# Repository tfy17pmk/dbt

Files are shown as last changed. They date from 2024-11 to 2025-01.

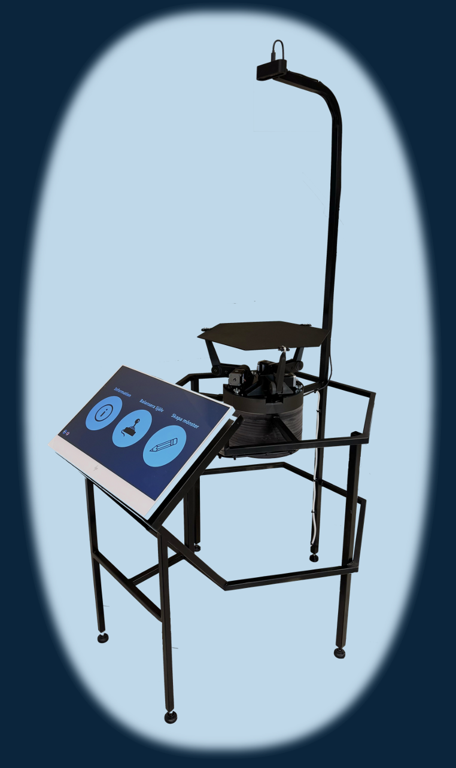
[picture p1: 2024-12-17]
GUI/assets/InfoPageOne.png

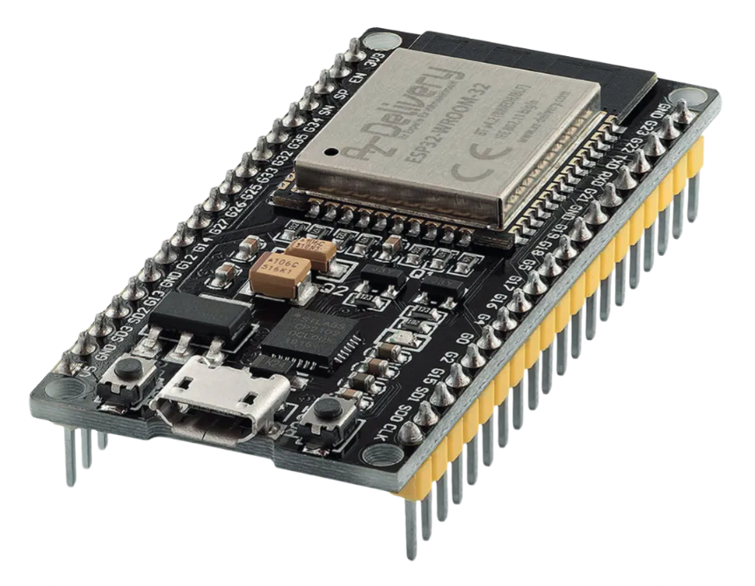
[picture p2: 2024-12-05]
GUI/assets/brain.png

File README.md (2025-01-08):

# DBT project, Ball Balancing Robot (Curiosum)

We are using Python virtual environment for development throughout the project. All the dependencies are defined in requirements.txt file, which ensures that everybody works with the same versions of dependencies. 

As for now, we have a single global virtual environment for the entire repo.

## Prerequisites

### Python version
Ensure that you use python3. Preferable version Python 3.11.2, but later versions should also be okay.

### Pip
Pip3 should be installed, if not, install with:
```
sudo apt update
sudo apt install python3-pip
pip3 --version (verify version)
```

## First setup:

### Creating environment
```
python3 -m venv dbt-venv (Linux)
python -m venv dbt-venv (Windows)
```

### Activating environment
```
source dbt-venv/bin/activate (Linux)
.\venv\Scripts\activate (Windows)
```

### Installing dependencies
```
pip install -r requirements.txt
```

## Everyday usage
Once virtual environment is created and dependencies are installed, you can follow the steps:

### Activate environment
```
source dbt-venv/bin/activate (Linux)
.\dbt-venv\Scripts\activate (Windows)
```

If you are using Windows, and get a problem with permission to run the Virtual Environment, use command:
```
Set-ExecutionPolicy Unrestricted -Scope Process
```
It can happen that you need to use it every time you open/reopen a new terminal session.

### Run applications within the environmet
```
python3 my_app.py (Linux)
python my_app.py (Windows)
```

### Deactivate environment
```
deactivate
```

## Updating dependencies
If there is a need to update the dependencies, add the new dependency to requirement.txt file.

### Update dependencies manually (Preferrable)
Add dependency on the new line in requirements.txt

### Update dependencies automatically
Otherwise, if you install the new dependency with
```
pip install new-dependency
```
add the new dependency to requirements.txt with
```
pip freeze > requirements.txt
```

OBS! Make sure to not add the dependencies that are not used/needed, if you intalled some now unused dependency before!

Don't forget to commit and push in the end of the day.

## Start program from new terminal
To start the program from a new terminal run the command:
```/home/curiadm/start_gui.sh```
It will start the program with the correct environment. 

## Maintenance of program
Password is the standard password. 
### Change text
To change the text of the pages go to ```GUI/constants.py``` here all text of the program is defined. If the text is changed be careful to check that the layout of the pages are still correct, or if the text has been changed to something that do not fit in the current canvas size. 

### Tune PID controller
Tips:

* Use a response curve to watch how the respons of the normalvector behaves. Needs good understanding of the code. 
* Write a standalone script based on the PID-process and communication while tuning. 
* Find a new plate that is truly flat that weights maximum 200g more than the current. 

## Program structure
The program uses two seperate processing devices and two different programming languages python and C++

* One Standard computer (python)
* One ESP 32 feather (C++)

The two processing devices communicate between each other using serial communication. The standard computer is responsible for running the GUI, performing image processing and performing most of the computations. The script is based around three processes and queues for robust communication between the processes. 

1. One process for navigation between the different pages in the GUI and performing the different functions in the backend of the buttons. For the backend functions in the GUI threads are also used in order to not block other functions like navigation to other pages while the ball is for instance performing a pattern. 

2. One process for performing the image analysis. The camera is started and in each frame the ball is found if there is a ball to be found. The coordnates of the ball is then put in a queue for easy access from other processes. 

3. One process for using the a PID controller to find the a new wanted normalvector of the plate. The PID controller accesses the ball coordinates in the queue and performs calculations using previous known position and current position. From this process a packet och data containing x- and y-component of the normalvector, the height of the plateand four uint_8 for controlling leds and if a homingroutine is to be run. The leds are however not implemented and used, just prepared the packet. 

The script in the ESP32 is more simple and straight forward. It is implemented using two classes and a main script. One class contains the inverse kinematics of the table, which allows easy and fast conversion between the normal vector of the plate to three motor angles. The second class governs the control of the motors. Acceleration of motors and calculates the maximum speed of each motor. The motors are then moved to the positions found by inverse kinematics. This is the performed continuos in the main script and when a new packet is received the calculationn is performed again. 

## Common errors
When the robot is plugged in a terminal window is automatically opened to allow printing of error messages

#### Camera not found
1. Check if the camera is plugged in (USB behind the screen) and on top of camera arm. 
2. Try restarting the robot (plug it out and in)
3. Change camera index, line 11 in ```webcamera.py```

#### ESP not found
Use the command ```ls /dev/tty*``` to find the port, should be named ```/dev/ttyUSB#```
1. Check if the ESP is plugged in (USB behind the screen) and micro USB underneath the robot connected to the ESP. 
2. Change the range of USB ports, line 10 in ```communication.py```

#### Lost count of steps
This error is not printed in the terminal but can be seen. The error is can be visualized if no ball is on the robot but the plate is not horizontal. 

1. Press one of the three micro switches located under the arms. This will perform the homing routine and the robot will find its steps again. 
2. Restart the robot will have the same effect. 

#### Weird starting up procedure
Sometimes  when the robots is plugged in it do not start normally. It allows the user to choose operating system. If this is the case. 

1. Wait for the timer to run out. 
2. If 1. did not work. pluggit out and in and choose the Ubuntu operating system the next time. 

#### Computer want to update
If the computer sends a message that it wants to update, just press close or remind me later.

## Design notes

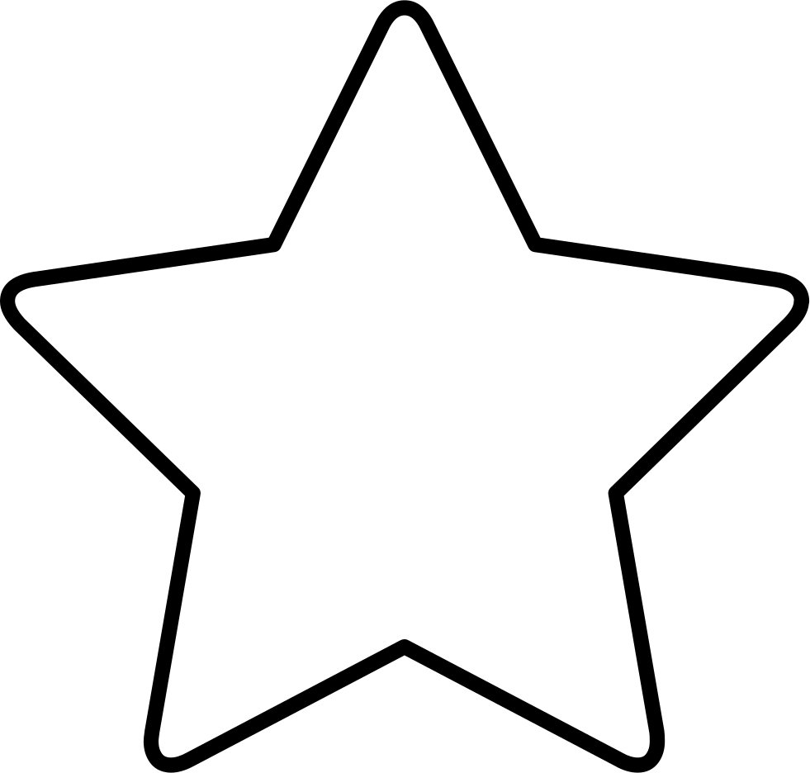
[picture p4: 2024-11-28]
GUI/assets/star.png

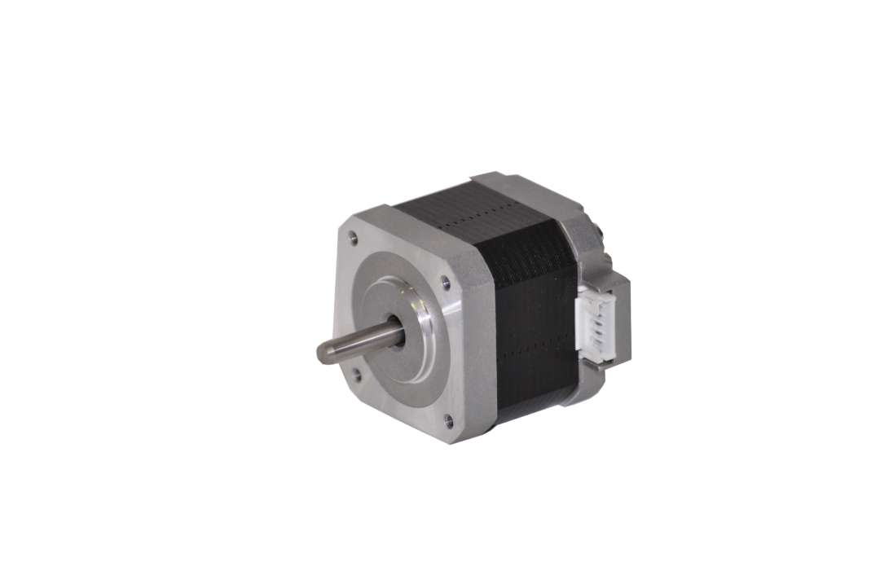
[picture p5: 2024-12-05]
GUI/assets/arm.png

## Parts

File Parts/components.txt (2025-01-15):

Camera:
    Logitech BRIO ultra HD pro
    https://www.logitech.com/sv-se/products/webcams/brio-4k-hdr-webcam.960-001106.html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

Computer:
    HP EliteOne

3st Stepper Motor:
    NEMA 17 SF2424-10B11
    https://www.elfa.se/sv/stegmotor-800nmm-2300min-sup-sup-nema-17-sanyo-denki-sf2424-10b11/p/30223848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
    
    Cable to motor:
        https://www.elfa.se/sv/bipolaer-motorkabel-med-tradar-500-mm-sanyo-denki-4835775/p/30159036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

3st Motor Driver:
    DRV8825
    https://www.electrokit.com/stegmotordrivare-drv8825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

    Capacitor: 100μF
    IMPORTANT: Dont forget to set the Vref on the driver, read the driver and motor documentation.

1st ESP32:
    HUZZAH32 ESP32 Feather
    https://www.elfa.se/sv/huzzah32-esp32-feather-kort-adafruit-3405/p/30139153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

1st PSU
    LRS-150F-36 154.8W 36V 4.3A
    https://www.elfa.se/en/embedded-switch-mode-power-supply-smps-154-8w-36v-3a-mean-well-lrs-150f-36/p/30044129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

6st BallBearing:
    Biltema 12x28x8mm
    https://www.biltema.se/bil---mc/bilreservdelar/kullager/kullager-6001-2rs-12x28x8-mm-2000050563

3st Rod End:
    Rod End 5mm Bore, 41mm Long Male Connection Gender
    https://se.rs-online.com/web/p/rod-ends/1852446

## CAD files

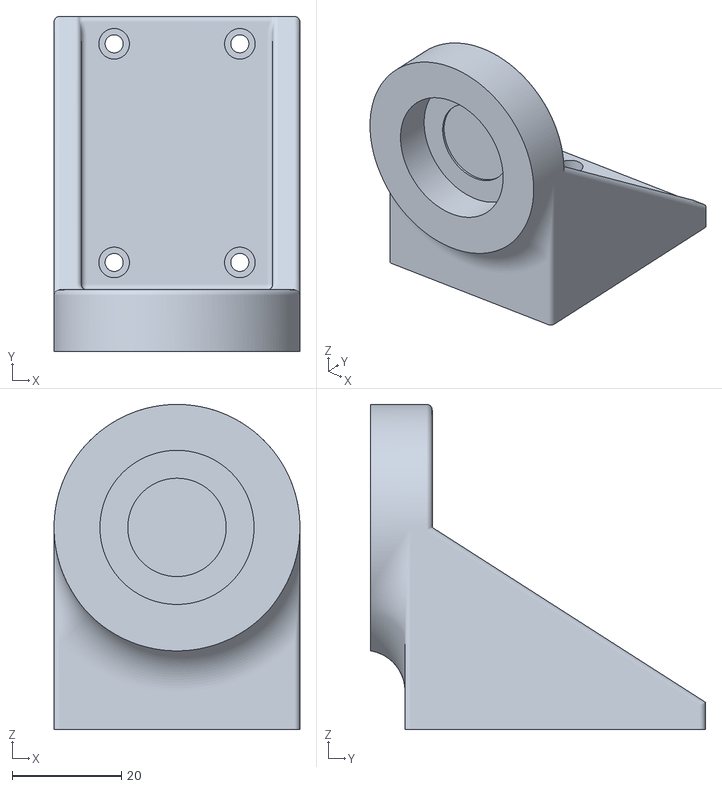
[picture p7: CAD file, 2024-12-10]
Parts/stl Files/Arm mounting/ArmMount.stl
45.0 x 61.3 x 59.5

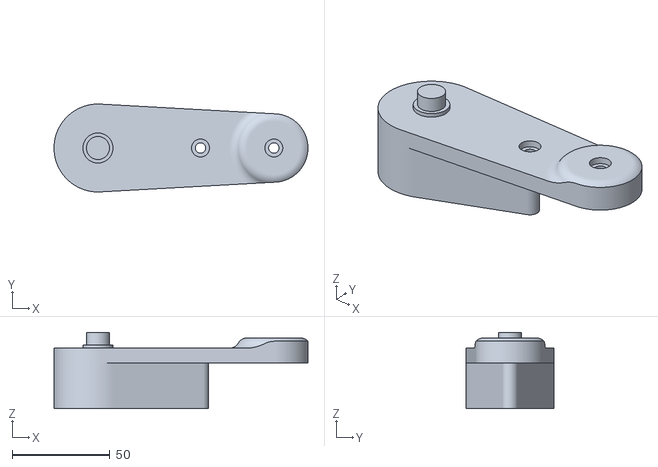
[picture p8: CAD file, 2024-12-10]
Parts/stl Files/Arm/LowerArmpartA.stl
130.0 x 45.0 x 38.9

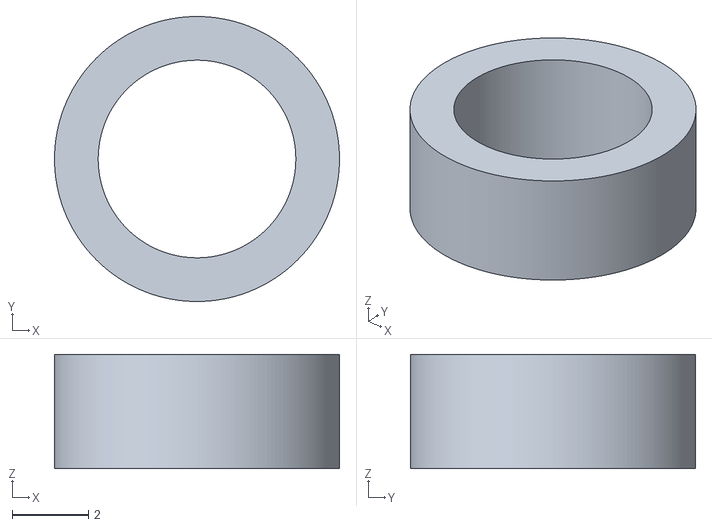
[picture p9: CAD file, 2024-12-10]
Parts/stl Files/Balance Plate Mounting Bracket/PlateBracketSpacer.stl
7.50 x 7.50 x 3.00

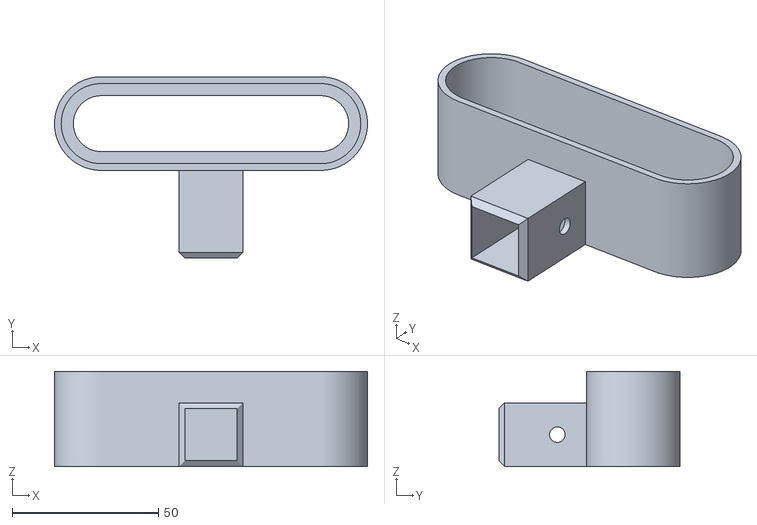
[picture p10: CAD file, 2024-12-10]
Parts/stl Files/CameraMount.stl
107.0 x 62.0 x 32.5

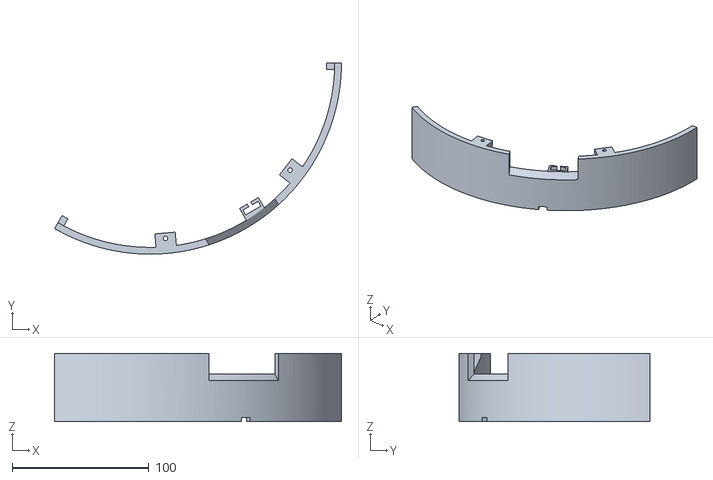
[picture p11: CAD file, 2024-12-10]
Parts/stl Files/Stand/StandPart2.stl
210.0 x 139.9 x 50.0

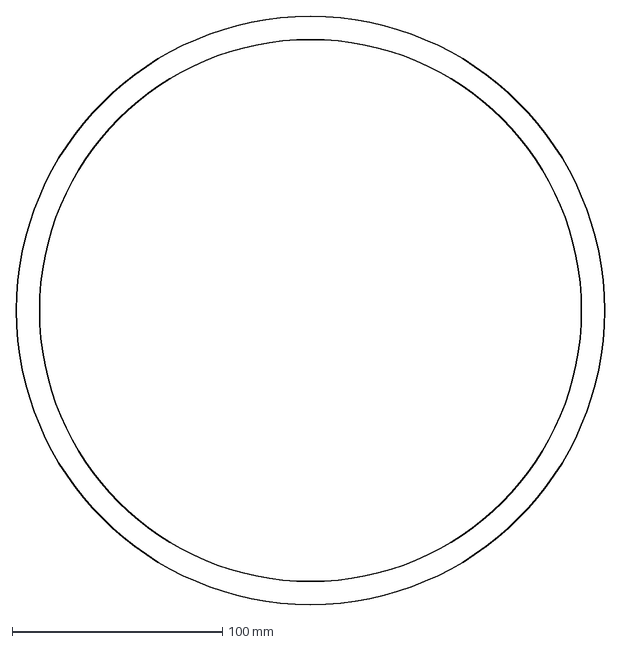
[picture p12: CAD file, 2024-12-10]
Parts/waterLaserCutting/12mmMDF/CircleBoxWall.dxf
280.0 x 280.0 mm

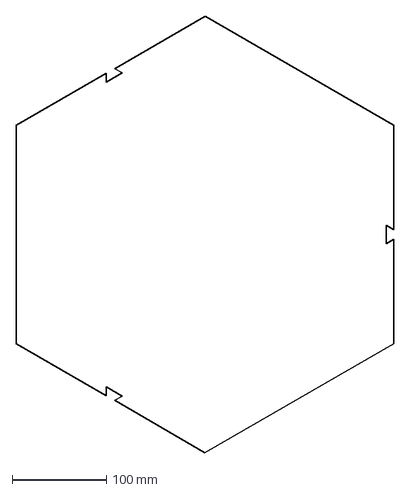
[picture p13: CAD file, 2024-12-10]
Parts/waterLaserCutting/3mmMDF/BalancePlate.dxf
400.0 x 461.9 mm

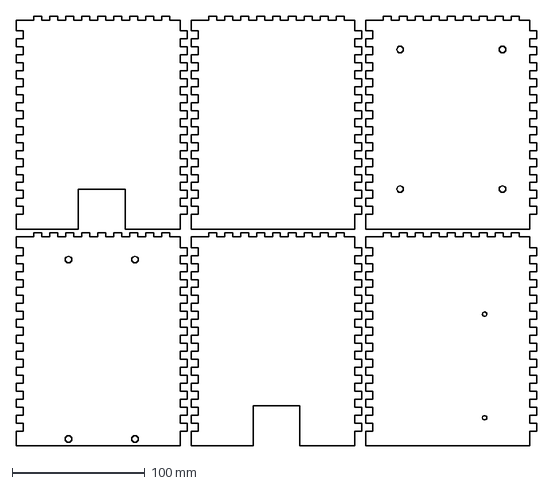
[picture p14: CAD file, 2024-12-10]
Parts/waterLaserCutting/3mmMDF/CirkularBoxInsert/SidePlates.dxf
391.4 x 323.0 mm

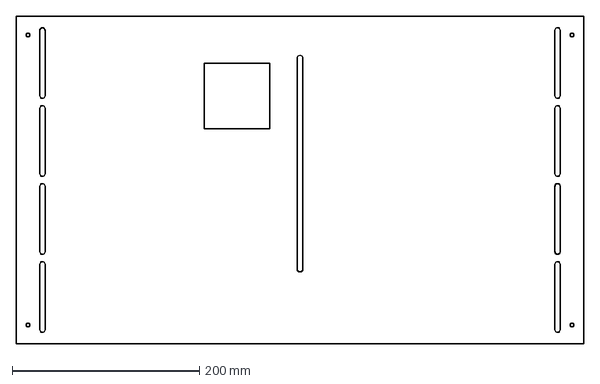
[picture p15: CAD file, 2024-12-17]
Parts/waterLaserCutting/metal/MonitorMountingPlate3mm.dxf
606.3 x 350.0 mm

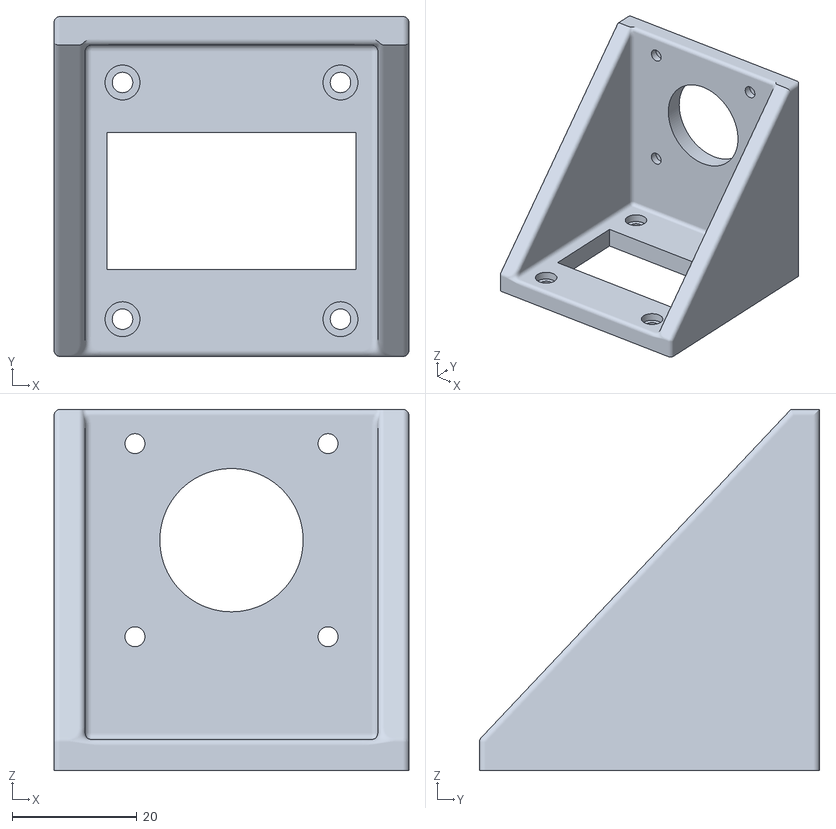
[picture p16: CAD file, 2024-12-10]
Parts/stl Files/Arm mounting/MotorBracket.stl
57.0 x 54.6 x 58.0

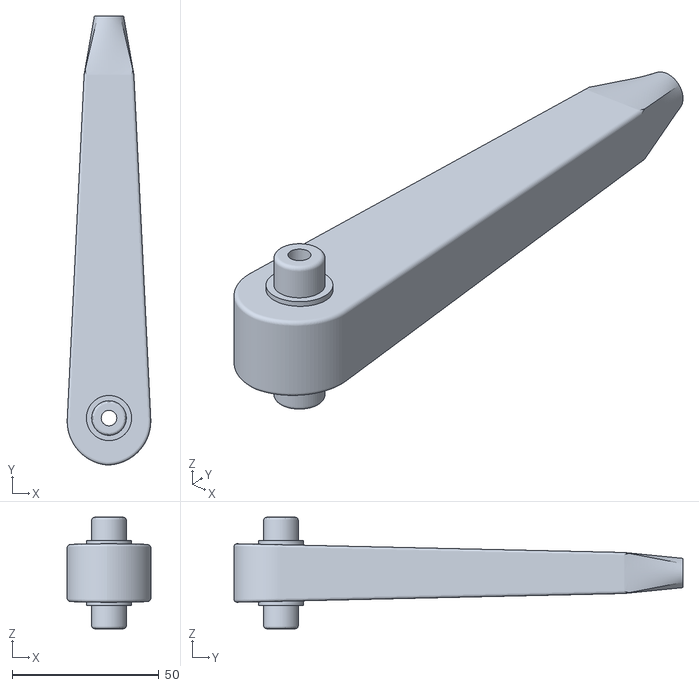
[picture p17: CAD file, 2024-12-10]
Parts/stl Files/Arm/UpperArm.stl
28.5 x 153.0 x 38.0

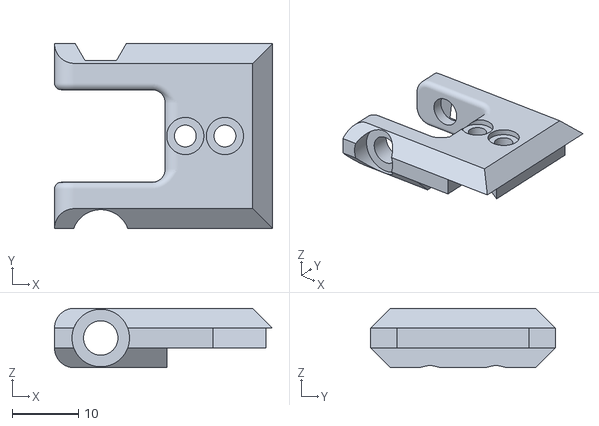
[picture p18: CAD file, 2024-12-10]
Parts/stl Files/Balance Plate Mounting Bracket/TopBracket.stl
33.0 x 28.0 x 9.00

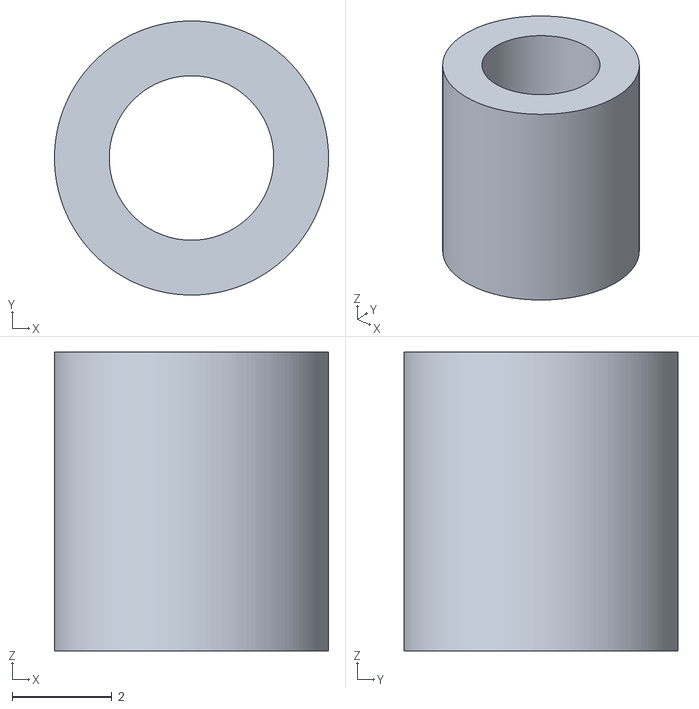
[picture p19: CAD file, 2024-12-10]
Parts/stl Files/PCBStandoff.stl
5.50 x 5.50 x 6.00

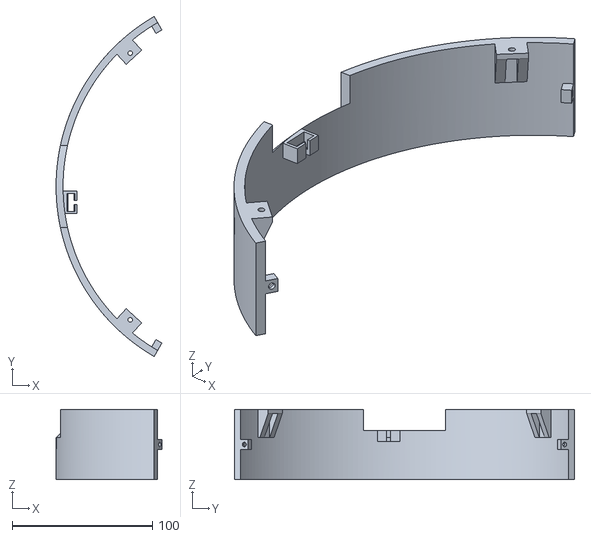
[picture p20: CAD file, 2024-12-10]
Parts/stl Files/Stand/StandPart1.stl
75.5 x 242.4 x 50.0

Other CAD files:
Parts/waterLaserCutting/3mmMDF/BottomRoundBox.dxf
Parts/waterLaserCutting/3mmMDF/CirkularBoxInsert/Bottom.dxf
Parts/waterLaserCutting/metal/MonitorCover1mm.dxf
Parts/stl Files/Arm/LowerArmpartB.stl
Parts/stl Files/Balance Plate Mounting Bracket/BottomBracket.stl
Parts/stl Files/CableClip.stl
Parts/stl Files/PSUcover.stl
Parts/stl Files/Stand/StandPart3.stl
Parts/waterLaserCutting/metal/ArmReinforsment3mm.dxf
Parts/waterLaserCutting/metal/BaseplateWithSmalerHoles3mm.dxf
Parts/waterLaserCutting/metal/FeetPlate3mm.dxf
Parts/waterLaserCutting/metal/LargeMetalRingWithMountingFlange3mm.dxf
Parts/waterLaserCutting/metal/MonitorMountPlate1mm.dxf
Parts/waterLaserCutting/metal/SmalMetalRingWithNotch3mm.dxf

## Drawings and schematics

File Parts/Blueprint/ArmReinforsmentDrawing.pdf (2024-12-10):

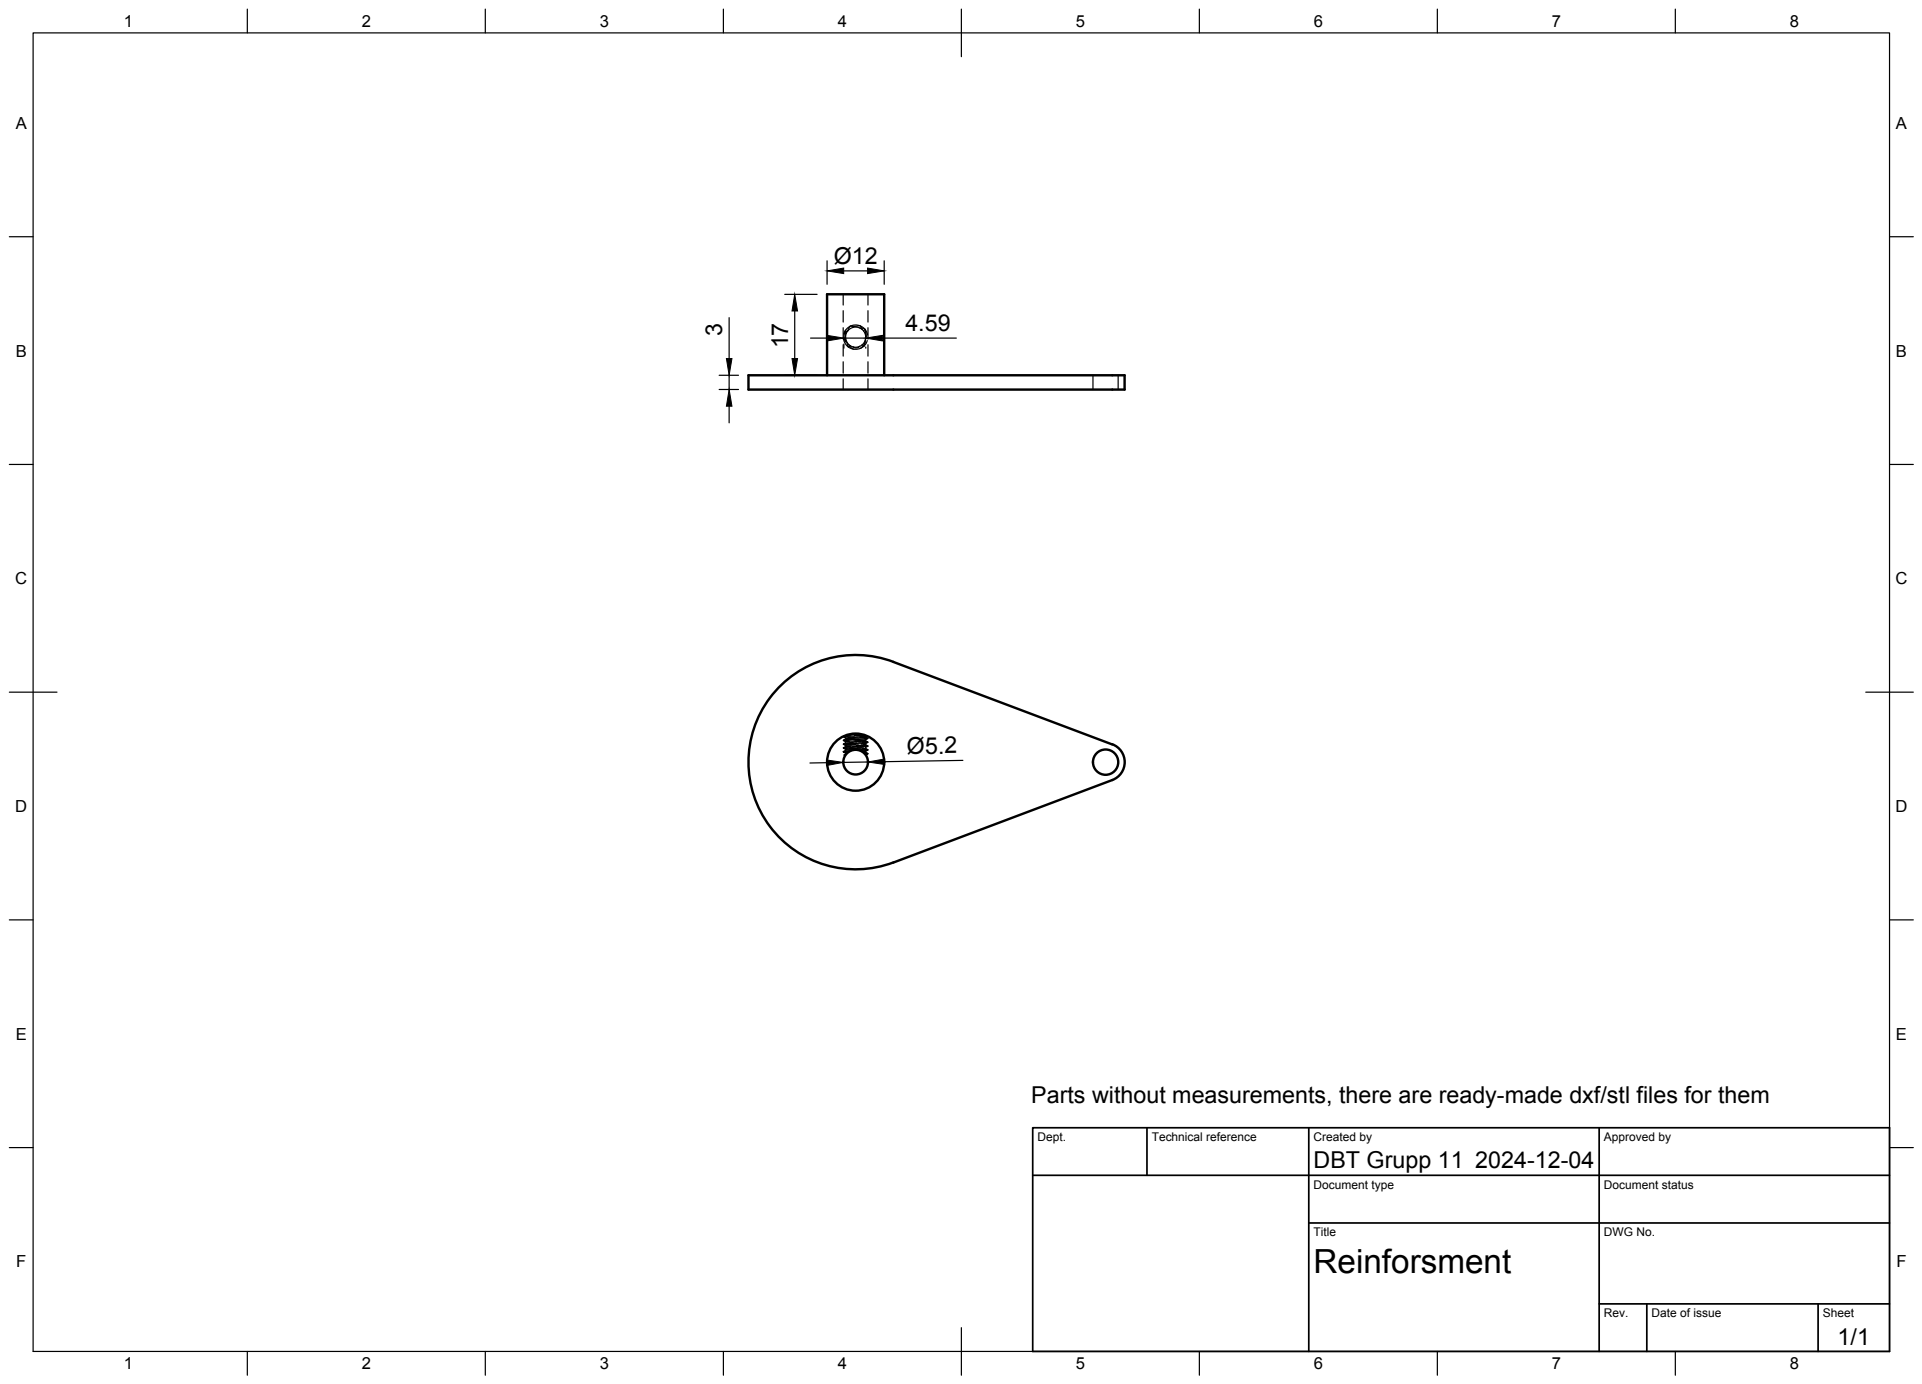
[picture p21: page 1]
Title; DWG No.; Rev.; Date of issue; Sheet

Parts without measurements, there are ready-made dxf/stl files for them

Dept. | Technical reference | Created by DBT Grupp 11 2024-12-04 | Approved by

Document type | Document status

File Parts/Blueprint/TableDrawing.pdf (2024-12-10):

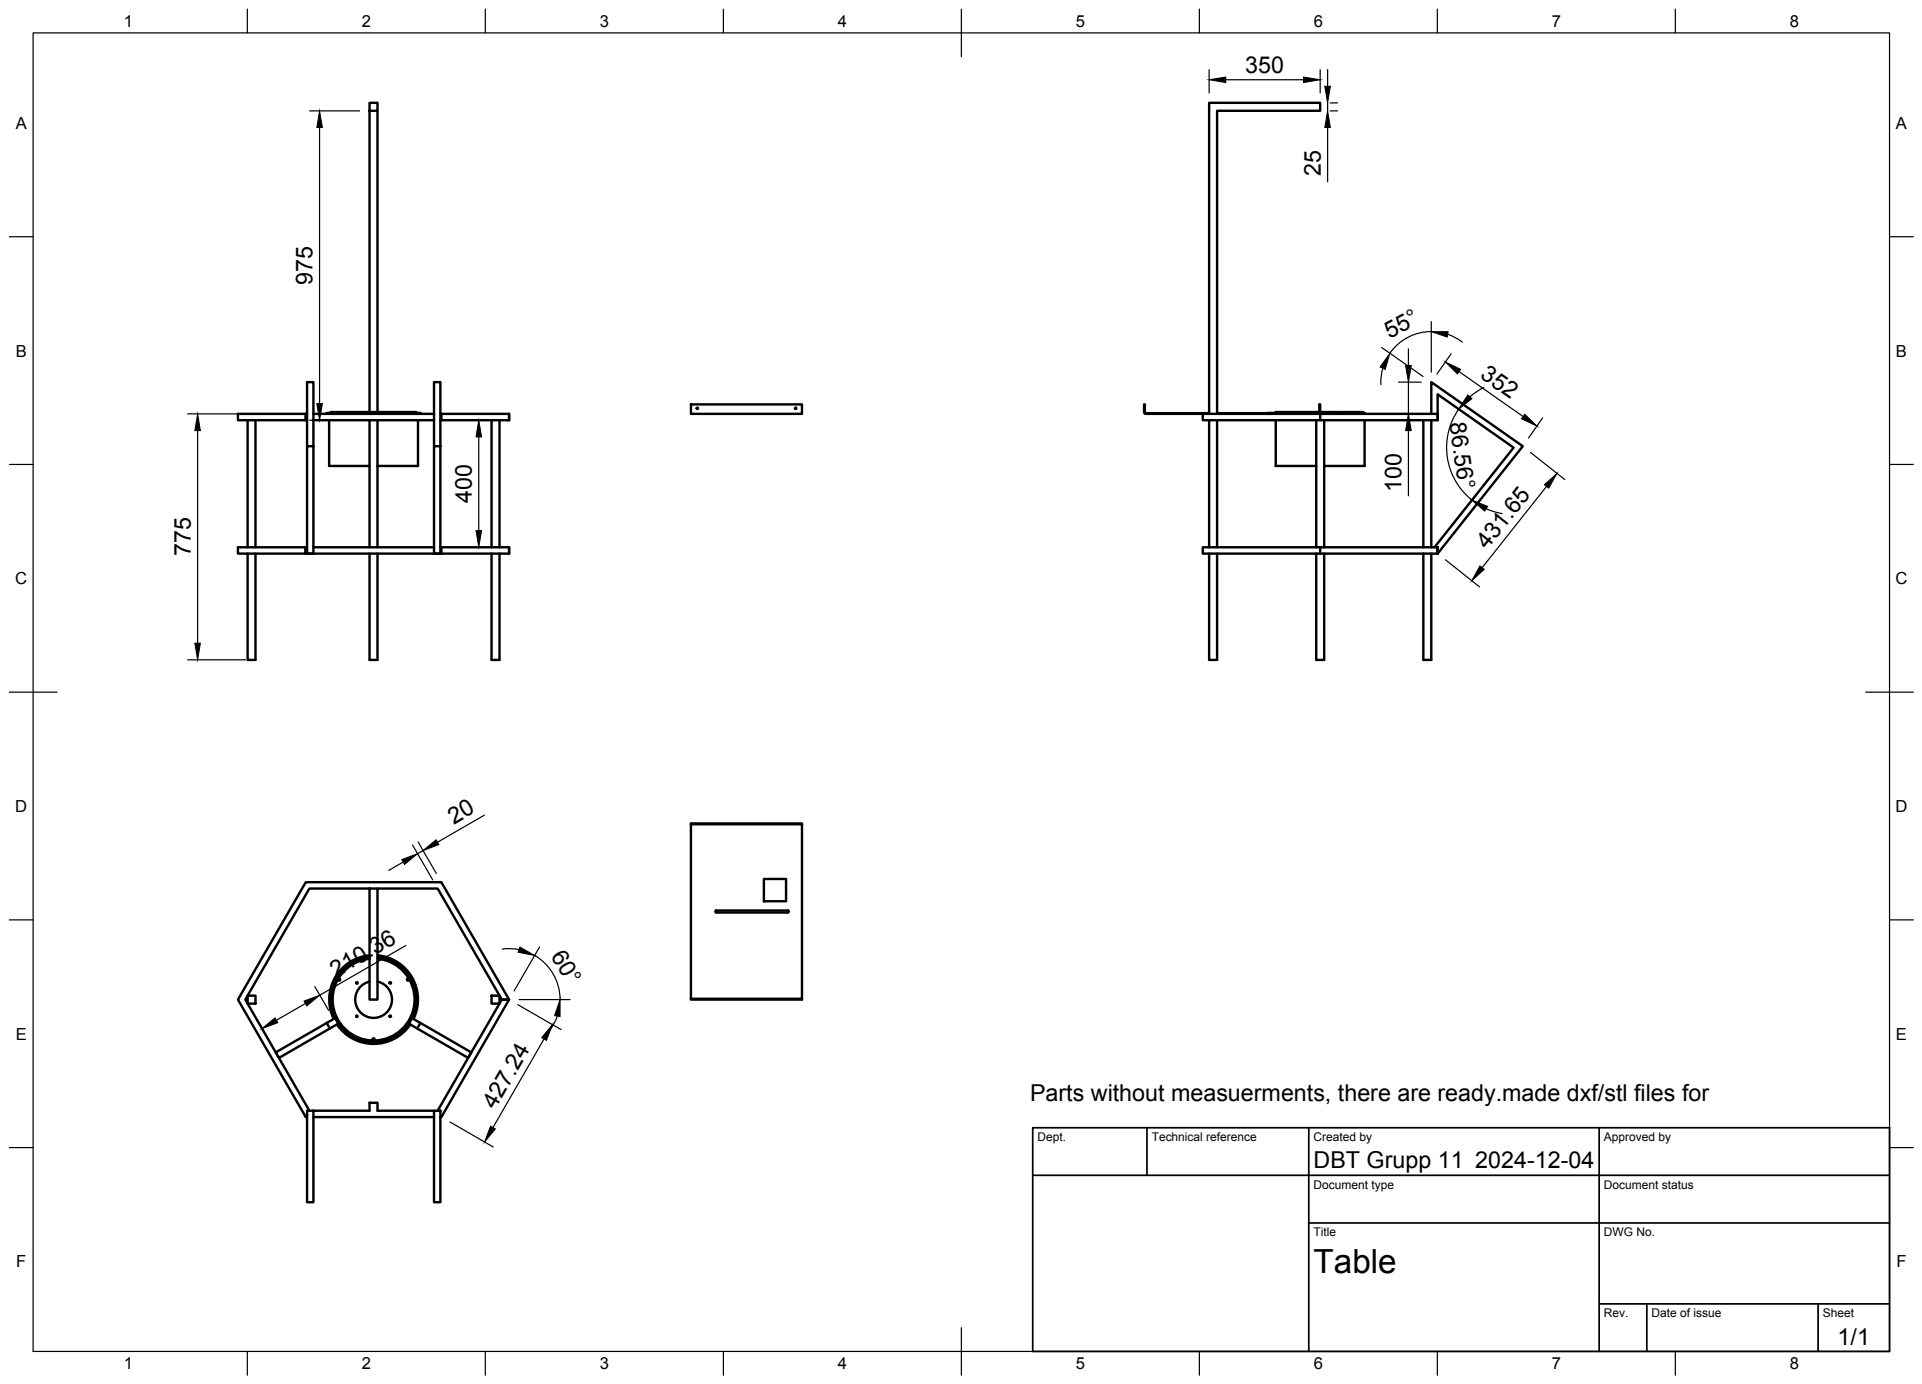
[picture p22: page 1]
Title; DWG No.; Rev.; Date of issue; Sheet; DBT Grupp 11 775

Parts without measuerments, there are ready.made dxf/stl files for

Dept. | Technical reference | Created by 2024-12-04 | Approved by

Document type | Document status

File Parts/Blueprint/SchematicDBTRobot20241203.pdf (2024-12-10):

A | A

1

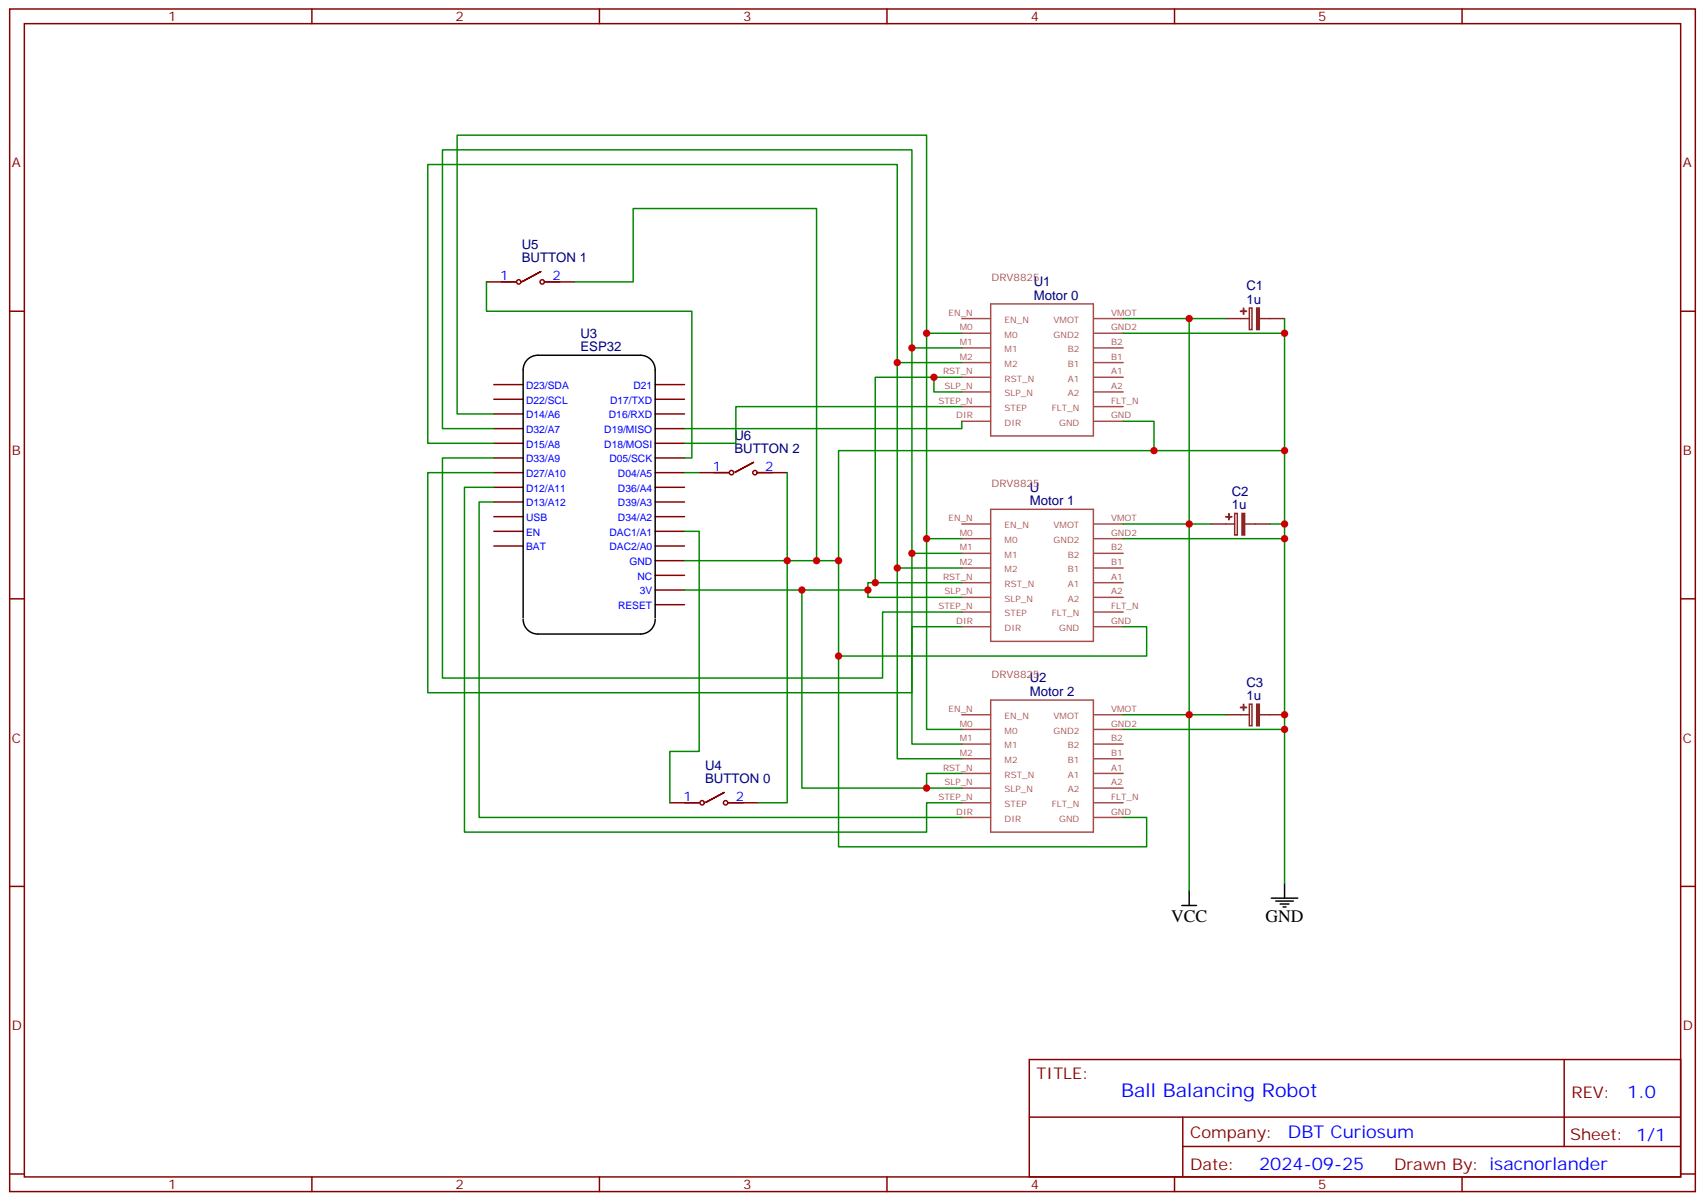
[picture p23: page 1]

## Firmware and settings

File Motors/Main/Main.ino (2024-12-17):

/*
 * This file is part of the ball ballancing robot.
 *
 * Developed for Curiosum during the design bulid test course, fall 2024 by 
 * project group 11.
 *
 * date: 4/12-2024
 */
#include "Arduino.h"
#include "Kinematics.h"
#include "Motors.h"
#include <AccelStepper.h>
#include <array>  // Include array library
#include <esp32-hal-cpu.h>
#include <HardwareSerial.h>

#define pi 3.1415926535

const uint8_t START_BYTE = 0x02;  

// Read the complete message (assuming 14 bytes total)
double normal_vector_x, normal_vector_y;
double height = 15;
uint8_t states_byte, homing_byte;
bool homing;
bool new_angles;

const size_t MESSAGE_LENGTH = 3 * sizeof(double) + 2 * sizeof(uint8_t);

double update_time;

Kinematics kinematics;
Motors motors;

// initialize stepper motors
std::array<AccelStepper, 3>& stepper = motors.setup_accel();
std::array<double, 3> motor_angles = {0,0,0};

// setup interupt for calibration buttons
void IRAM_ATTR handleButtonPress1() {

  if(!homing){
    homing = true;
    motors.home();
    homing = false;
  }else {
    motors.buttonPressed[0] = true;  // Set flag when the button is pressed
  }
}

void IRAM_ATTR handleButtonPress2() {
  if(!homing){
    homing = true;
    motors.home();
    homing = false;
  }else {
    motors.buttonPressed[1] = true;  // Set flag when the button is pressed
  }
}

void IRAM_ATTR handleButtonPress3() {
  if(!homing){
    homing = true;
    motors.home();
    homing = false;
  }else {
    motors.buttonPressed[2] = true;  // Set flag when the button is pressed
  }
}

void setup() {

  Serial.begin(115200);
  setCpuFrequencyMhz(240);

  motors.buttonPressed.fill(false);
  motors.skipPhaseOne.fill(false);

  pinMode(motors.buttonPin[0], INPUT_PULLUP);
  attachInterrupt(digitalPinToInterrupt(motors.buttonPin[0]), handleButtonPress1, RISING);

  pinMode(motors.buttonPin[1], INPUT_PULLUP);
  attachInterrupt(digitalPinToInterrupt(motors.buttonPin[1]), handleButtonPress2, RISING);

  pinMode(motors.buttonPin[2], INPUT_PULLUP);
  attachInterrupt(digitalPinToInterrupt(motors.buttonPin[2]), handleButtonPress3, RISING);

  // initialize position
  homing = true;
  motors.home(); 
  homing = false;
}

/*
* Description: Recieves and unpacks data send from the large computer.  
*
* Input: None
*
* Output: None
*/
void receiveData() {
  // Wait for the start byte
  if ((Serial.available() > 0) && Serial.read() == START_BYTE) {
    unsigned long startTime = millis();

    // Wait until the complete message is available or a timeout occurs
    while (Serial.available() < MESSAGE_LENGTH - 1) {
      if (millis() - startTime > 1000) { // 1-second timeout
        Serial.flush();
        return;
      }
    }

    // Read and unpack the data
    Serial.readBytes((char*)&normal_vector_x, sizeof(double));
    Serial.readBytes((char*)&normal_vector_y, sizeof(double));
    Serial.readBytes((char*)&height, sizeof(double));
    Serial.readBytes((char*)&states_byte, 1);
    Serial.readBytes((char*)&homing_byte, 1);
    Serial.flush();

    // Process the data
    bool state1 = (states_byte & 0b100) >> 2;
    bool state2 = (states_byte & 0b010) >> 1;
    bool state3 = (states_byte & 0b001);
    homing = homing_byte == 1;
  }
  return;
}

void loop() {

  receiveData(); // receive data
  if (homing == true){
    // home and find position
    motors.home();
    homing = false;
  } else {

    // calculate motor angles
    motor_angles = kinematics.setPosition(normal_vector_x, normal_vector_y, height); 

    // set motor angles
    motors.set_angle(motor_angles.data());
    
    update_time = millis();
    // Run latets set position in 2ms
    while (millis() - update_time < 2){
      stepper[0].run();
      stepper[1].run();
      stepper[2].run();
    }
  }
}

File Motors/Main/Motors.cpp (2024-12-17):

/*
 * This file is part of the ball ballancing robot.
 *
 * Developed for Curiosum during the design bulid test course, fall 2024 by 
 * project group 11.
 *
 * date: 4/12-2024
 */
#include "AccelStepper.h"
#include "Arduino.h"
#include "Motors.h"

// Constructor to initialize motors with mode, direction, and step pins
Motors::Motors() {
    for (int i = 0; i < 3; i++) {

      pinMode(_MODE[i], OUTPUT);
      pinMode(_DIR[i], OUTPUT);
      digitalWrite(_STEP[i], LOW); // Initialize step pins to low
      digitalWrite(_MODE[i], _RESOLUTION[i]);
    }
}


std::array<AccelStepper, 3>& Motors::setup_accel() {
  AccelStepper tmp_stepper1(AccelStepper::DRIVER, _STEP[0], _DIR[0]);  // Set up the AccelStepper for DRV8825
  AccelStepper tmp_stepper2(AccelStepper::DRIVER, _STEP[1], _DIR[1]);  // Set up the AccelStepper for DRV8825
  AccelStepper tmp_stepper3(AccelStepper::DRIVER, _STEP[2], _DIR[2]);  // Set up the AccelStepper for DRV8825
  
  stepper[0] = tmp_stepper1;
  stepper[1] = tmp_stepper2;
  stepper[2] = tmp_stepper3;
  return stepper;
}

/*
* Description: Performs first phase of the homing routine, moves arms down until buttons are pressed. 
*
* Input: None
*
* Output: None
*/
void Motors::phase1() {

  std::array<bool, 3> first_time;
  first_time.fill(true);
  

  for(int i = 0; i < 3; i++) {
    // Configure the stepper motor for the initial slow homing phase
    stepper[i].setMaxSpeed(2000);       // Slow movement toward the switch
    stepper[i].setAcceleration(1000);   // Slow acceleration for initial approach
    // Homing phase 1: Move slowly toward the button (limit switch)
    stepper[i].setSpeed(1000);          // Slow speed toward the switch
  }
      
  while (!buttonPressed[0] || !buttonPressed[1] || !buttonPressed[2]) {  // Move until the button is pressed

    if(!buttonPressed[0] && !skipPhaseOne[0]) {
      stepper[0].runSpeed();
    }else {
      phase2(0, first_time[0]);
      first_time[0] = false;
    }

    if(!buttonPressed[1] && !skipPhaseOne[1]) {
      stepper[1].runSpeed();
    }else {
      phase2(1, first_time[1]);
      first_time[1] = false;
    }

    if(!buttonPressed[2] && !skipPhaseOne[2]) {
      stepper[2].runSpeed();
    }else {
      phase2(2, first_time[2]);
      first_time[2] = false;
    }

  }

  for(int i = 0; i < 3; i++) {
    if(first_time[i]) {
      phase2(i, first_time[i]);
    }
  }
  buttonPressed.fill(false);
}

/*
* Description: Performs second phase of the homing routine, moves arms up a small amount. 
*
* Input: a motor and if it is the first time, which implies that maxspeed and acceleration has to be set.
*
* Output: None
*/
void Motors::phase2(int motor, bool first_time) {

  // Homing phase 2: Move back faster with higher acceleration
  if(first_time) {
    // Increase acceleration for faster back-off
    stepper[motor].setMaxSpeed(4000);           // Increase max speed significantly
    stepper[motor].setAcceleration(1000);
    int backOffSteps = 90;                      // Approximate number of microsteps for 10 degrees (1/32 microstepping)
    stepper[motor].move(-backOffSteps);         // Move back by 10 degrees
  }else if(stepper[motor].distanceToGo() != 0) {
    stepper[motor].run();                       // Run the motor while it backs off
  }
}

/*
* Description: Performs third phase of the homing routine, moves arms down again slowly and then go to initial position 
*
* Input: None
*
* Output: None
*/
void Motors::phase3() {

  buttonPressed.fill(false);
  std::array<bool, 3> saved_pos;
  saved_pos.fill(false);

  for(int i = 0; i < 3; i++) {
    // Configure the stepper motor for the initial slow homing phase
    stepper[i].setMaxSpeed(200);      // Slow movement toward the switch
    stepper[i].setAcceleration(50);   // Slow acceleration for initial approach
    stepper[i].setSpeed(100);         // Slow speed toward the switch
  }
      
  while (!buttonPressed[0] || !buttonPressed[1] || !buttonPressed[2]) {  // Move until the button is pressed

    if(!buttonPressed[0]) {
      stepper[0].runSpeed();
    }else {
      stepper[0].setCurrentPosition(3700); 
      saved_pos[0] = true;
    }

    if(!buttonPressed[1]) {
      stepper[1].runSpeed();
    }else {
      stepper[1].setCurrentPosition(3700);
      saved_pos[1] = true;
    }

    if(!buttonPressed[2]) {
      stepper[2].runSpeed();
    }else {
      stepper[2].setCurrentPosition(3700);
      saved_pos[2] = true;
    }

  }

  for(int i = 0; i < 3; i++) {
    if(!saved_pos[i]) {
      stepper[i].setCurrentPosition(3700);
    }
  }

}

/*
* Description: Performs a homing routine, where endpoint of motion boundary are found, adn thereby performs a calibration
*
* Input: None
*
* Output: None
*/
void Motors::home() {

  skipPhaseOne.fill(false);
  for(int i = 0; i < 3; i++) {
    if(digitalRead(buttonPin[i]) == HIGH) {
      skipPhaseOne[i] = true;
    }
  }
  
  bool homingComplete = false;
  buttonPressed.fill(false);

  phase1();

  //finish/run phase 2 depending on if the button is pressed from the beginning.
  while(stepper[0].distanceToGo() != 0 || stepper[1].distanceToGo() != 0 || stepper[2].distanceToGo() != 0) {
    for(int i = 0; i < 3; i++) {

      if(stepper[i].distanceToGo() != 0) {
        phase2(i, false);
      }
    }
  }

  phase3();

  initial_position();
}

/*
* Description: Sets initial position of table
*
* Requirement: A succesfull homing routine has to be performed to find initial position succesfully
*
* Input: None
*
* Output: None
*/
void Motors::initial_position() {

  for(int i = 0; i < 3; i++) {
    stepper[i].setMaxSpeed(4000);   // Increase max speed significantly
    stepper[i].setAcceleration(3000);
    stepper[i].moveTo(3200);   
  }
  while((stepper[0].currentPosition() != 3200) || (stepper[1].currentPosition() != 3200) || (stepper[2].currentPosition() != 3200)){
    stepper[0].run();
    stepper[1].run();
    stepper[2].run();
  }
}

/*
* Description: Calculates max speed of each motor and constrains it to be within boundaries
*
* Input: Wanted motor position in steps
*
* Output: None
*/
void Motors::set_speed(double steps[3]) {
  for (int i = 0; i < 3; i++) {
    _speedPrev[i] = speed[i];                                                                 //sets previous speed
    position[i] = stepper[i].currentPosition();                                               //sets current position
    _diff[i] =  abs(position[i] - steps[i]);                                                  //claculate the difference between current and target position of motor
    speed[i] = _diff[i] * _diff[i] * _cs;                                                    
    speed[i] = constrain(speed[i], _speedPrev[i] - _speed_diff, _speedPrev[i] + _speed_diff); //filters speed by constraining the speed to have a maximum differeence to previous 
    speed[i] = constrain(speed[i], 0, _max_speed);                                            // constrain maxspeed to be within boundaries
    }
}
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

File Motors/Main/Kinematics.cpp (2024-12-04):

/*
 * This file is part of the ball ballancing robot.
 *
 * Developed for Curiosum during the design bulid test course, fall 2024 by 
 * project group 11.
 *
 * date: 4/12-2024
 */
#include "Arduino.h"
#include <stdio.h>
#include <array>
#include <math.h>
#include "Kinematics.h"

#define pi 3.1415926535

Kinematics::Kinematics() {
}

/*
* Description: Calculates motor angles from the normal vector of the table
*
* Input: which leg, height of table, normal vector component in x and y direction. 
*
* Output: motor angle in degrees
*/
double Kinematics::thetas(int leg, double hz, double nx, double ny) {

    //create unit normal vector
    nmag = sqrt(pow(nx, 2) + pow(ny, 2) + 1);  //magnitude of the normal vector
    nx /= nmag;
    ny /= nmag;
    nz = 1 / nmag;

    switch (leg) {
    case leg1:  //Leg A
      _y = _d + (_e / 2) * (1 - (pow(nx, 2) + 3 * pow(nz, 2) + 3 * nz) / (nz + 1 - pow(nx, 2) + (pow(nx, 4) - 3 * pow(nx, 2) * pow(ny, 2)) / ((nz + 1) * (nz + 1 - pow(nx, 2)))));
      _z = hz + _e * ny;
      _mag = sqrt(pow(_y, 2) + pow(_z, 2));
      _angle = acos(_y / _mag) + acos((pow(_mag, 2) + pow(_f, 2) - pow(_g, 2)) / (2 * _mag * _f));
      break;
    case leg2:  //Leg B
      _x = (sqrt(3) / 2) * (_e * (1 - (pow(nx, 2) + sqrt(3) * nx * ny) / (nz + 1)) - _d);
      _y = _x / sqrt(3);
      _z = hz - (_e / 2) * (sqrt(3) * nx + ny);
      _mag = sqrt(pow(_x, 2) + pow(_y, 2) + pow(_z, 2));
      _angle = acos((sqrt(3) * _x + _y) / (-2 * _mag)) + acos((pow(_mag, 2) + pow(_f, 2) - pow(_g, 2)) / (2 * _mag * _f));
      break;
    case leg3:  //Leg C
      _x = (sqrt(3) / 2) * (_d - _e * (1 - (pow(nx, 2) - sqrt(3) * nx * ny) / (nz + 1)));
      _y = -_x / sqrt(3);
      _z = hz + (_e / 2) * (sqrt(3) * nx - ny);
      _mag = sqrt(pow(_x, 2) + pow(_y, 2) + pow(_z, 2));
      _angle = acos((sqrt(3) * _x - _y) / (2 * _mag)) + acos((pow(_mag, 2) + pow(_f, 2) - pow(_g, 2)) / (2 * _mag * _f));
      break;
  }
  return (_angle * (180 / pi));  //converts angle to degrees and returns the value
}
/*
* Description: Constrain normal vector component in x and y direction and compute motor angles 
*
* Input: normal vector component in x and y direction and the height of the table
*
* Output: motor angles in degrees
*/
std::array<double, 3> Kinematics::setPosition(double normal_vector_x, double normal_vector_y, double _height) {
  // Set boundaries for table angles
  if (normal_vector_x > _max_normal_x) {
    normal_vector_x = _max_normal_x;
  }
  else if (normal_vector_x < _min_normal_x) {
    normal_vector_x = _min_normal_x;
  }

  if (normal_vector_y > _max_normal_y) {
    normal_vector_y = _max_normal_y;
  }
  else if (normal_vector_y < _min_normal_y) {
    normal_vector_y = _min_normal_y;
  }
  

  
  motor_angles[0] = thetas(leg1, _height, normal_vector_x, normal_vector_y); // return degree
  motor_angles[1] = thetas(leg2, _height, normal_vector_x, normal_vector_y);
  motor_angles[2] = thetas(leg3, _height, normal_vector_x, normal_vector_y);


  return motor_angles;
}

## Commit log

2024-10-09 Inverse kinematics (#2)
    * Add class for kinematics with implementation of inverse kinematics
    * Review modifications.
    * Add method for angles between normal plane and xy plane
    ---------
2024-10-11 Add Class for motors and script for setup of pins
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2024-10-16 Class for inverse kinematics in c++, not currently compatible with arduino
2024-10-16 Add main for kinematics and motors in arduino code, cleared up old scripts
2024-10-16 lagt till arduinokoden i en mapp och gjort små ändingar i motor.cpp och motor.h för att ta med resolution
2024-10-16 Add c++ code for running motors, not working but compiles
    [Main.ino, Motors.cpp, Motors.h]
2024-10-18 added the function for homing the stepper motors
2024-10-21 Added functionallity to home the stepper motors if they alredy is at the bottom
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2024-10-24 Add new kinematics implementation and table angles to motor angles
2024-10-27 Add new kinematics and implementation of go to specific angles
    implementation to differnet angles is very slow
2024-10-29 made the home screen and added dummy png images for the buttons
2024-10-30 Created competition page. Still requires addition of images on buttons
2024-10-30 Added the arrows to the next and previus buttons in the info page
2024-10-30 Added the text for every page in the info frame, and change the layout some
2024-10-30 Add a class for button and a beginning for the pattern page
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2024-11-01 modified the button class to take images or text, and added new images
2024-11-01 change size of the arrow buttons and moved stuff around
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2024-11-01 moved eyes image so it waset cut off, and fixt som bugs
2024-11-01 Add hexagonal drawing board in pattern page and images on buttons for patterns
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2024-11-04 Add motors run at higher speed to requested position
2024-11-05 added the comunucation function and so the light buttons on the info page sends the commands to turn on and turn off the lights
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2024-11-05 Fix using serial for comm and normal vector for control
    [Kinematics.cpp, Kinematics.h, Main.ino]
2024-11-07 Add motor speed according to distance from goal
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2024-11-08 Deleted python code for kinematics, because we use c++ version now.
2024-11-08 Fix clean up in main for arduino
    [Main.ino]
2024-11-08 Removed unused files and directories. Renamed initial directory to Motors from Main.
2024-11-12 Komenterade bort de två raderna som har med ESP'n att göra i communication vilket är raderna 7 och 30
2024-11-12 Added a functions that maps the canvas frame coordinates into camera frame coordinates
2024-11-12 Add reset function for pid
2024-11-12 Fix tune motor speed
    [Kinematics.h, Motors.cpp, Motors.h]
2024-11-13 Made it so predefined buttons returns remapped coordinates and also replaced the predefined circle with a hexagon.
    [pyvenv.cfg]
2024-11-13 Changed the circle icon on the circle-pattern button to a hexagon because now it makes a hexagon shape on the canvas instead.
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2024-11-13 Added print to be used as an interupt. Also removed a function thatdid the same thing as clear_all.
2024-11-13 Remade the class completely and made it so the class-function takes current_pos and a queue as input and process through the queue in a way that it returns only one set of coordinates for the PID to 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
2024-11-13 Made it so that when one presses the Ångra button the variable mapped_points is set to (0,0)
2024-11-13 Fix tuning of motorspeed
    [Motors.cpp, Motors.h]
2024-11-13 Removed venv, modified .gitignore
    [pyvenv.cfg]
2024-11-14 FIX investigate weird behaviour for stopping motors
    [Main.ino, Motors.cpp, Motors.h]
2024-11-19 when the back button was pressed it change color so it became invisebile
2024-11-19 Fix stopping motors and tuning of speed
    [Main.ino, Motors.cpp, Motors.h]
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2024-11-20 Changed the bakground to a picture on the kome_page, also commented away the code that calls on the challange_page in the GUI file since the code cant run om my computer with the camera. I also impor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
2024-11-20 Added coupling between main and info_page in GUI. The video stream can now be shown on page 1 of info_page.
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2024-11-21 adding background to the patterns page, must add bg to the buttons to
2024-11-21 Har fixat problemet att challenge sidan kraschar dator
    [communication.py]
2024-11-21 Fixed thread handling in info_page. Attempt to remove update_frames() and let the thread to update the frame in GUI directly.
2024-11-21 Terminating threads and GUI in main if KeyboardInterrupt occures. Added docstrings to functions that did not have it in main, info_page and GUI.
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2024-11-21 Add correct PID constants for new PId implementation
2024-11-21 added comunication between the patterns page and the PID process, and created a new thread to handle sending goal positions in different time intervalls
2024-11-21 fixt bug with communication between pattern and PID, the thread handeling comunication was onely started in init but when you left pattern page the tread was joind but never started agein
2024-11-27 Fixed stop event for keyboard interrupt.
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2024-11-28 Fixed thread problem in challange page. It only creates ones and terminates when Keyboard interrupt occurs.
2024-11-28 Added two buttons for two new patterns. Heart and star. Also adjusted text layout in freeplay.
2024-12-03 Added timer to GUI for going back to Home Page after 3 minutes of inactivity.
2024-12-04 Added support for both SE and EN and two buttons on the home page to change between them, also removed the chalange page and commented out the code just in case
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2024-12-04 Fixed Keyboard Interrupt problem. We can now exit program with Ctrl+C without zombie processes.
2024-12-05 Made the circular buttons on the home page just be clickable on the circle and not the entire canvas
2024-12-10 Added all the parts and blueprints of the robot
    [ArmMount.stl, ArmReinforsment3mm.dxf, BalancePlate.dxf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]
2024-12-10 fixed Windows naming error
    [ArmReinforsment3mm.dxf, BalancePlate.dxf, BaseplateWithSmalerHoles3mm.dxf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]
2024-12-10 Added comments to challenge_page and class_challenges in the case of future development
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2024-12-11 Deleted test_code and Queue_processer directories. Deleted unused pid class in pid.py. Commented class_PID, changed variable and method names to snake case, applied those changes in main.py, where th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
2024-12-11 Removed redundant communication.py files from Motors and GUI directories. Removed unused communication references in info_page.
2024-12-12 Change all static text to text from the json object inside of constants, and removed prints from all the files
2024-12-17 added the cutting profile for the monitor cover and the uppdated monitor mounting plate
    [MonitorCover1mm.dxf, MonitorMountingPlate3mm.dxf]
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2024-12-17 Fixed and rescaled patterns to be on plate
2024-12-18 Fix changed wording and deleted a print
2024-12-19 Fix reset PID after joystick
2025-01-08 Add normal errors in read me
    [communication.py]
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
